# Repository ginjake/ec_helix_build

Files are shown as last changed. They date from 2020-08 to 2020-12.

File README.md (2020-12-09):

## LICENSE
creative commons non commercial

商用利用したい場合は twitter @sirojake にご相談ください  
please contact me for commercial use.
## developer 
ginjake

## 静電容量Helixとは？
Helix Keyboardの基板を差し替え、静電容量スイッチに対応させる為の基板です   
Varmiloスイッチ用とラバードーム用の2種類があり、別々の基板になっています。

## 外部の使用ライブラリ
### シンボルライブラリー
phi-kbd-library-master https://github.com/zk-phi/phi-kbd-library  
kbd https://github.com/foostan/kbd  

### フットプリントライブラリー
kbd https://github.com/foostan/kbd  
phi-kbd-library-master https://github.com/zk-phi/phi-kbd-library  
rd https://github.com/KiCad/kicad-footprints/tree/master/Resistor_SMD.pretty  
cs　https://github.com/KiCad/kicad-footprints/tree/master/Capacitor_SMD.pretty  

# 組み立て方 
本家Helixとの共通部分については省略しています。  
Varmilo版とラバードームで共通箇所が多いため、まとめて記載しています。

こちらのビルドログも参考になるので、目を通しておくと良いかもしれません  
https://orumin.blogspot.com/2020/10/helix-ec-helix-niz-ver.html

## 注意
本キットは組み立て難易度が高く、使うパーツも特殊です。  
自作キーボード初心者の方にはおすすめしません。  
通常のメカニカルスイッチでは動作せず、特殊なスイッチが必要になります。

# Varmiloスイッチについて
Varmilo社が出しているスイッチで、静電容量メカニカルとも呼ばれています。  
単体では販売されていないので、既製品を分解して入手する必要があります。  
ふもっふのお店のカスタムキーボードサービスで
デイジー軸 桜軸 ローズ軸などを選択して発注するのが一番手軽です。
https://jp.varmilo.com/keyboardproscenium/

# ラバードームスイッチについて
HHKBやREAL FORCE、NiZで採用されている方式です。  
トップハウジング、ステム、ラバードーム、コニックリングで構成されており、  
NiZキーボードを購入して分解することで全て手に入れることが出来ます。

## 部品

下記は両手分を作るのに必要なパーツ数です  

### 本家 Varmilo ラバードーム共通部品
| 名前 | 数 | 備考 |
| ---- | ---- | --- |
| Pro Micro | 2個 | |
| TRRSジャック | 2個 | |
| タクトスイッチ | 2個 | |
| スプリングピンヘッダ 12P | 4個 | コンスルーとも呼ばれています |
| プレート | 2セット| 遊舎工房の切り出しサービスがおすすめです|
| OLED保護プレート | 2枚 | |
| ゴム足 | 12個 |  |
| キーキャップ | 64個 | CherryMX軸 |
| 3.5mmオーディオケーブル | 左右合わせて1本 | 左右のキーボード接続用 |
| micro USBケーブル | 左右あわせて1本 | 
| OLEDモジュール | 2個 | OLED用（オプション） |
| ピンソケット 4P | 2個 | OLED用（オプション） |
| ピンヘッダ 4P | 2個 | OLED用（オプション） |
| M2スペーサー 8mm | 4個 | (OLED用)|
| sk6812mini| varmilo版 64個,ラバードーム版 54個  | LEDを付ける場合のみ|

### ラバードーム版追加部品
| 名前 | 数 | 備考 |
| ---- | ---- | --- |
| M5スペーサー | 8個 | |
| M2用ワッシャ | 8個(適宜) | |
| M2スペーサー 7mm| 8個 | |
| M2ネジ 4mm| 16個 | (低頭のほうが望ましい)|
| M2ネジ 6mm| 8個 | (低頭のほうが望ましい)|

### 本家と異なる部品
| 名前 | 数 | 備考 | 入手先 |
| ---- | ---- | --- | ---- |
| PCB | 2枚 | | |
| 静電容量キースイッチ | 64個 | 詳しくは後述します | |
| スイッチソケット | 64個 | varmilo版のみ https://yushakobo.jp/shop/a01ps/ | |
| 1608(0603)チップ抵抗 100K | 14 | | https://www.sengoku.co.jp/mod/sgk_cart/detail.php?code=EEHD-57HD |
| 1608(0603)チップ抵抗 10K | 4 | | https://www.sengoku.co.jp/mod/sgk_cart/detail.php?code=EEHD-57GX |
| 1608(0603)チップ抵抗 1KΩ | 4| | https://www.sengoku.co.jp/mod/sgk_cart/detail.php?code=EEHD-57GK |
| 1608(0603)チップ抵抗 200Ω | 12 | | https://www.sengoku.co.jp/mod/sgk_cart/detail.php?code=EEHD-57FZ |
| 1608(0603)チップ抵抗 51KΩ | 2 | | https://www.sengoku.co.jp/mod/sgk_cart/detail.php?code=EEHD-57H7 |
| 1608チップ積層セラミックコンデンサー 50Vdc 220pF | 2 | GRM1882C1H221JA01D*A (10個入り)| https://www.marutsu.co.jp/GoodsDetail.jsp?salesGoodsCode=19297&shopNo=3 |
|チップトランジスタ　2SC2712-GR 50V150m | 2 | | http://akizukidenshi.com/catalog/g/gI-00761/ |
| 74HC4051DB IC MUX/DEMUX 8X1 16SSOP | 2 | | https://www.marutsu.co.jp/pc/i/24340308/ |
| 2回路入オペアンプAD8616ARM | 2 | | http://akizukidenshi.com/catalog/g/gI-04570/ |
| ジャンパ用の銅線 | 少し | | |

### Varmilo版用キースイッチ
対応スイッチはVarmiloのECスイッチのみです。  
V1でもV2でも動作します。  

### Niz版用キースイッチ
メカニカルスイッチと異なり、複数のパーツが組み合わさって機能します。

| 名前  | 主な入手先 |
| ----  | ---- |
| 軸＆ハウジング  | https://www.nizkeyboard.com/collections/ornaments/products/2019-new-niz-ec-switch |
| ラバードーム  |  https://www.keyclack.com/products/bke-topre-dome-replacements?_pos=2&_sid=6025d869e&_ss=r もしくはREAL FORCEやNiz、HHKBから解体 |
| コニックリング | REAL FORCEやNiz、HHKB等から解体、もしくは https://btoshop.jp/2020/09/25/adelcps/ |

### ビットトレード版のスイッチについて
コニックリングとラバードームのみ対応しています。  
外形がcherryMXの企画と比べて若干大きいため、プレートが割れるなどの可能性があります。  
(アクリルカットサービスのモノは入りましたが、初期版のモノでは割れてしまいました。)  
ワッシャーが入らない等の問題もあるのでハウジングは使わず、コニックリングの回収に留めておくのが無難かもしれません。 
スペーサーやネジ、プレートを調整すれば使えるとは思います。  

## 追加で必要な工具
| 名前 | 数 | 備考 | 入手先 |
| ---- | ---- | --- | ---- |
| 絶縁テープ | 1つ | | |
| フラックス | 1つ | | |
| 拡大用ルーペ | 1つ | | |
| 懐中電灯 | 1つ | | |

## 組み立て方
右手用と左手用で若干異なります。  
写真は基本的にVarmilo版ですが、ラバードーム版でもほぼ同じです。    
ラバードーム版とVarmilo版はスイッチ部分のフットプリントが異なるだけです。   

__一度全ての工程を読み、理解してから作業を進めることをお勧めします。__

OLED,TRRSジャック等のHelixの共通部分については省略します。  
LEDについてはbacklightのみの対応です。  
(Varmilo版とラバードーム版で数が異なります)

## 絶縁テープとジャンパ(左手側のみ)
将来的にProMicroが刺さるところに絶縁テープを貼ります  


絶縁テープの上から、写真のようにジャンパしていきます。
この作業は左手側のみで、右手は不要です。   


ジャンパが完了したら、その上からさらに絶縁テープを貼った方が安心です。

また、絶縁テープを貼らず、ProMicro側を表裏逆転させる方法もありますが  
OLED用のスペーサーの高さが変わってしまうのであまりおすすめしません。

## その他のパーツを実装する
基板に書いてある通りにパーツを実装します。
IMAG7291

74HC4051DB　と オペアンプAD8616ARMの向きには注意してください。  
チップ側の黒い丸上の凹みと、基板上のコの時のシルクが合わさるように置くのが正解です。  
隣のピンとショートしていないか、懐中電灯で照らしながらルーペで確認しておくのがおすすめです。


## リセットスイッチ
本家と同じです。

## スイッチソケットをつける(Varmilo版)
Varmilo版の場合、全てのキーにスイッチソケットをつけていきます。


## OLEDをつける(オプション)
本家と同じです

## TRRSジャックをつける
両手分つくる場合は必要になります。  
本家と同じです

## ProMicro
本家と同じです。

## ProMicroにqmkを焼く
下記のファームウェアを焼く必要があります。  
現在はNiz版とVarmilo版は同じファームになっています。   
https://github.com/ginjake/qmk_firmware/tree/ec_helix_niz   
``make ec_helix:test:avrdude`` もしくは 
``make ec_helix:ginjake:avrdude`` 

## トッププレート Varmilo版
トッププレートとスペーサーをネジ(短い方)で固定したら、向きに注意してスイッチを埋めていきます。

## トッププレート ラバードーム版
トッププレートにワッシャとスペーサーをネジ(短い方)で固定してから、スイッチをアクリルに差込みます。  
ワッシャはスペーサー1つに対して1枚が基本ですが、ネジやスペーサーの長さ、アクリルの太さによって変化します。
このあたりは適宜調整してください。
ネジ→トッププレート→ワッシャ→スペーサー　のような順番になるように固定しましょう。  
中に軸を入れてラバードームでフタをします。  
スペーサーとラバードームが干渉しないよう、ハサミで切りましょう  
ラバードームの凹みの中にコニックリングを入れます。  


このとき、コニックリングが重ね合っていないか気を付けましょう。  
複数個が重なっていても意外と気付かず、誤作動の原因になります。  

## ボトムプレート(ラバードーム版)
基板とボトムプレートの間にM5スペーサーが入るようにネジ止め(長い方)しましょう。  
Varmilo版は普通にネジで止めてしまって大丈夫です。


## 完成


## qmkコンパイル時の諸注意
・OLEDをつけない場合は `rule.mk` の `OLED_DRIVER_ENABLE` を `no` にしてください。 
無駄な負荷がかかり、取りこぼしが発生する可能性が高くなります。   
・Varmilo版とラバードーム版でledの数が異なります。 `config.h` の `RGBLED_NUM` の数を適宜変更してください

・ステンレスプレートを使う場合は　`config.h` の `#define STAINLESS_PLATE` のコメントアウトを外してください。ステンレスプレートは実験的な対応の為、動作保証対象外となります。

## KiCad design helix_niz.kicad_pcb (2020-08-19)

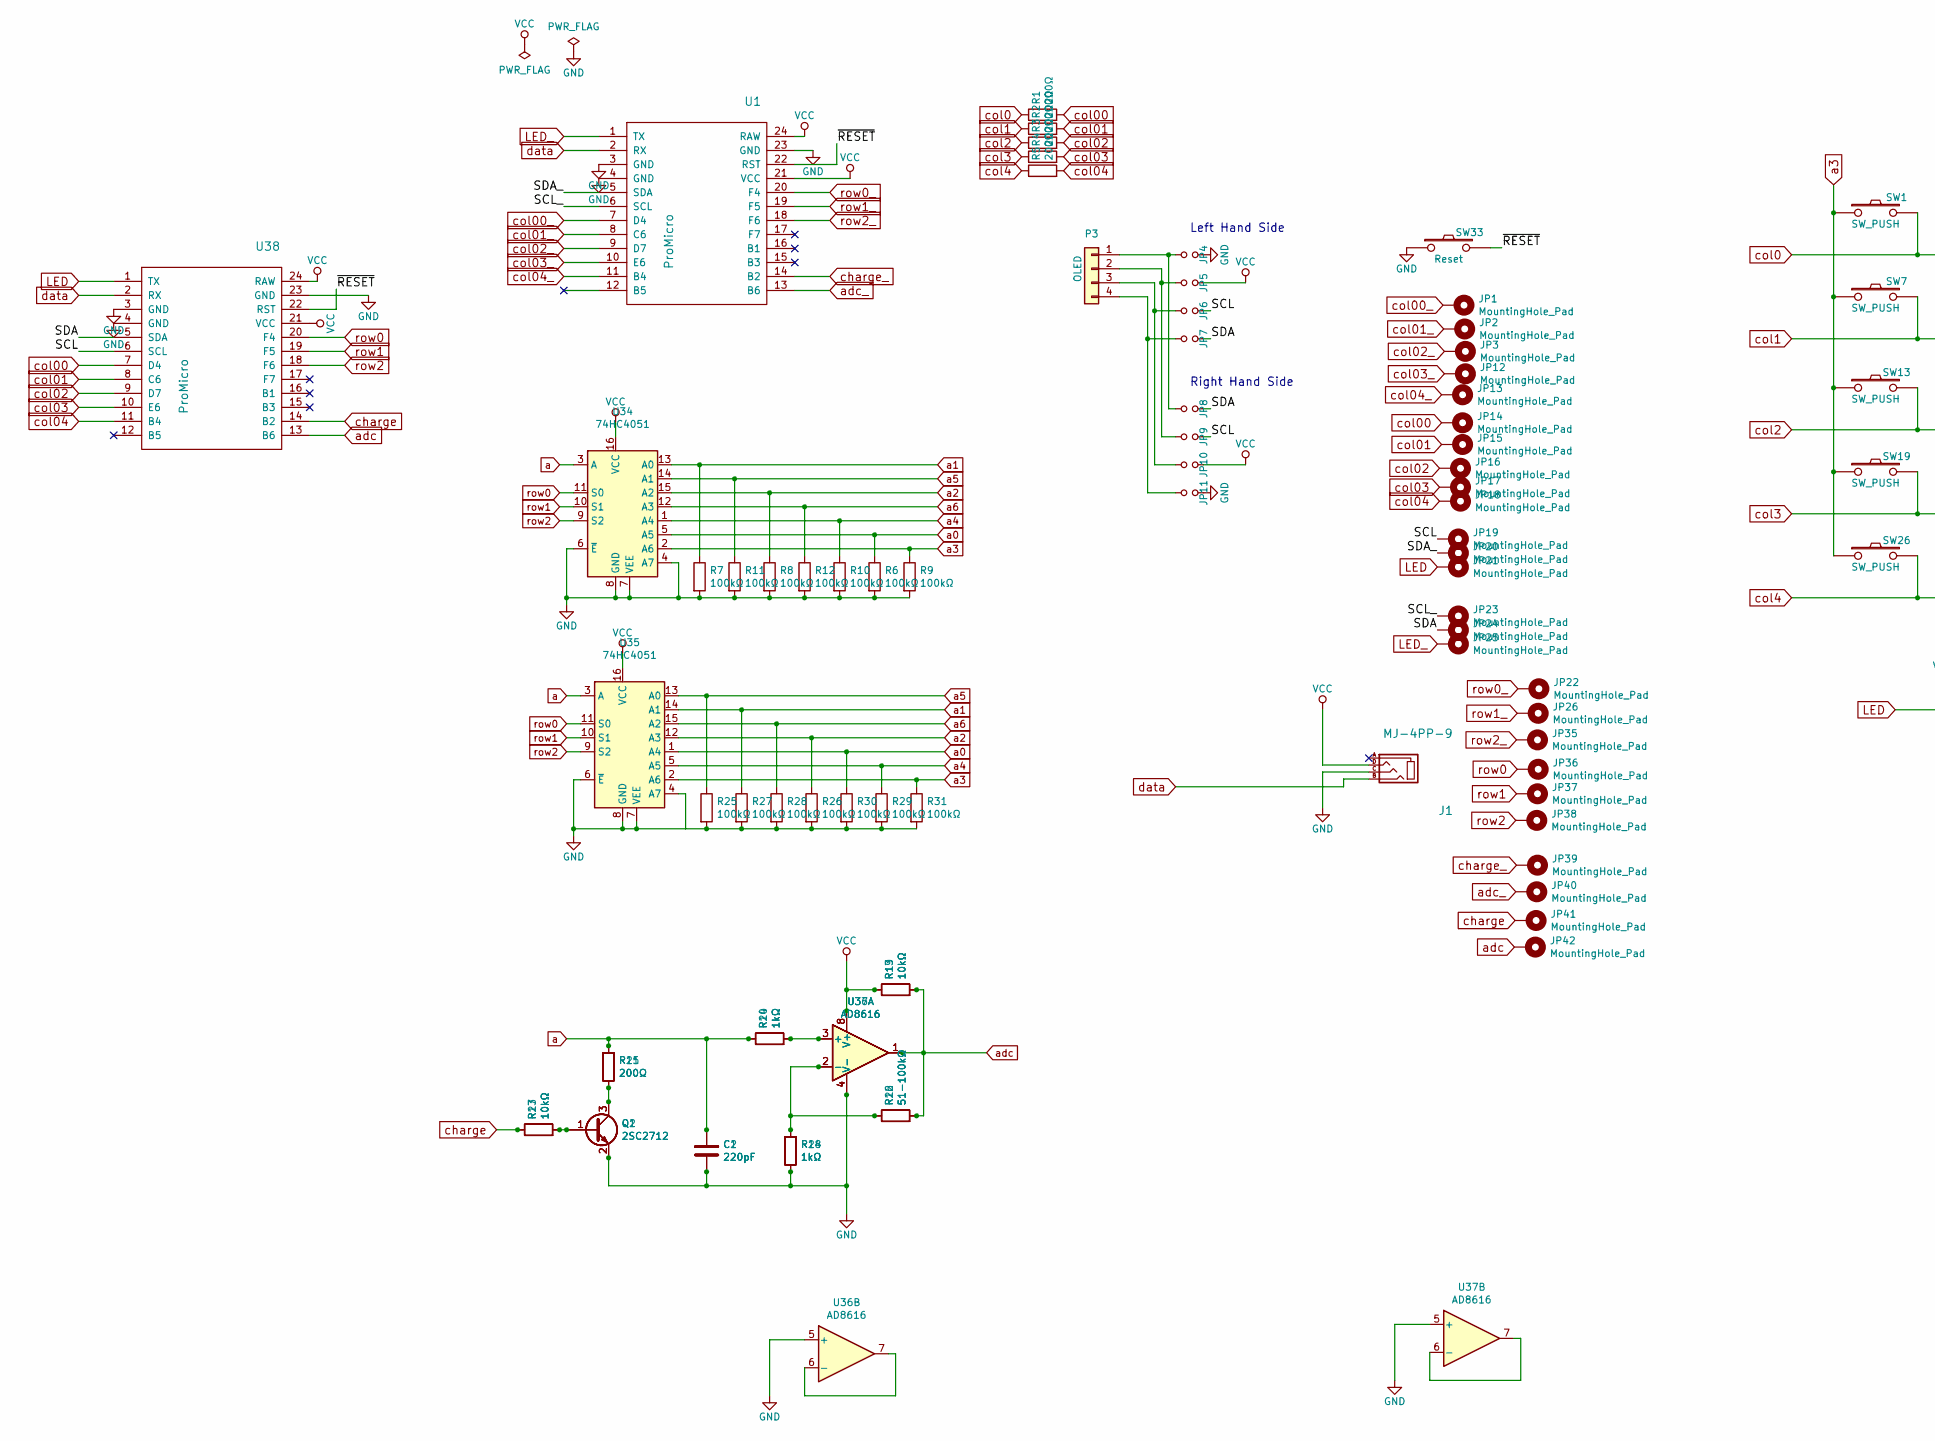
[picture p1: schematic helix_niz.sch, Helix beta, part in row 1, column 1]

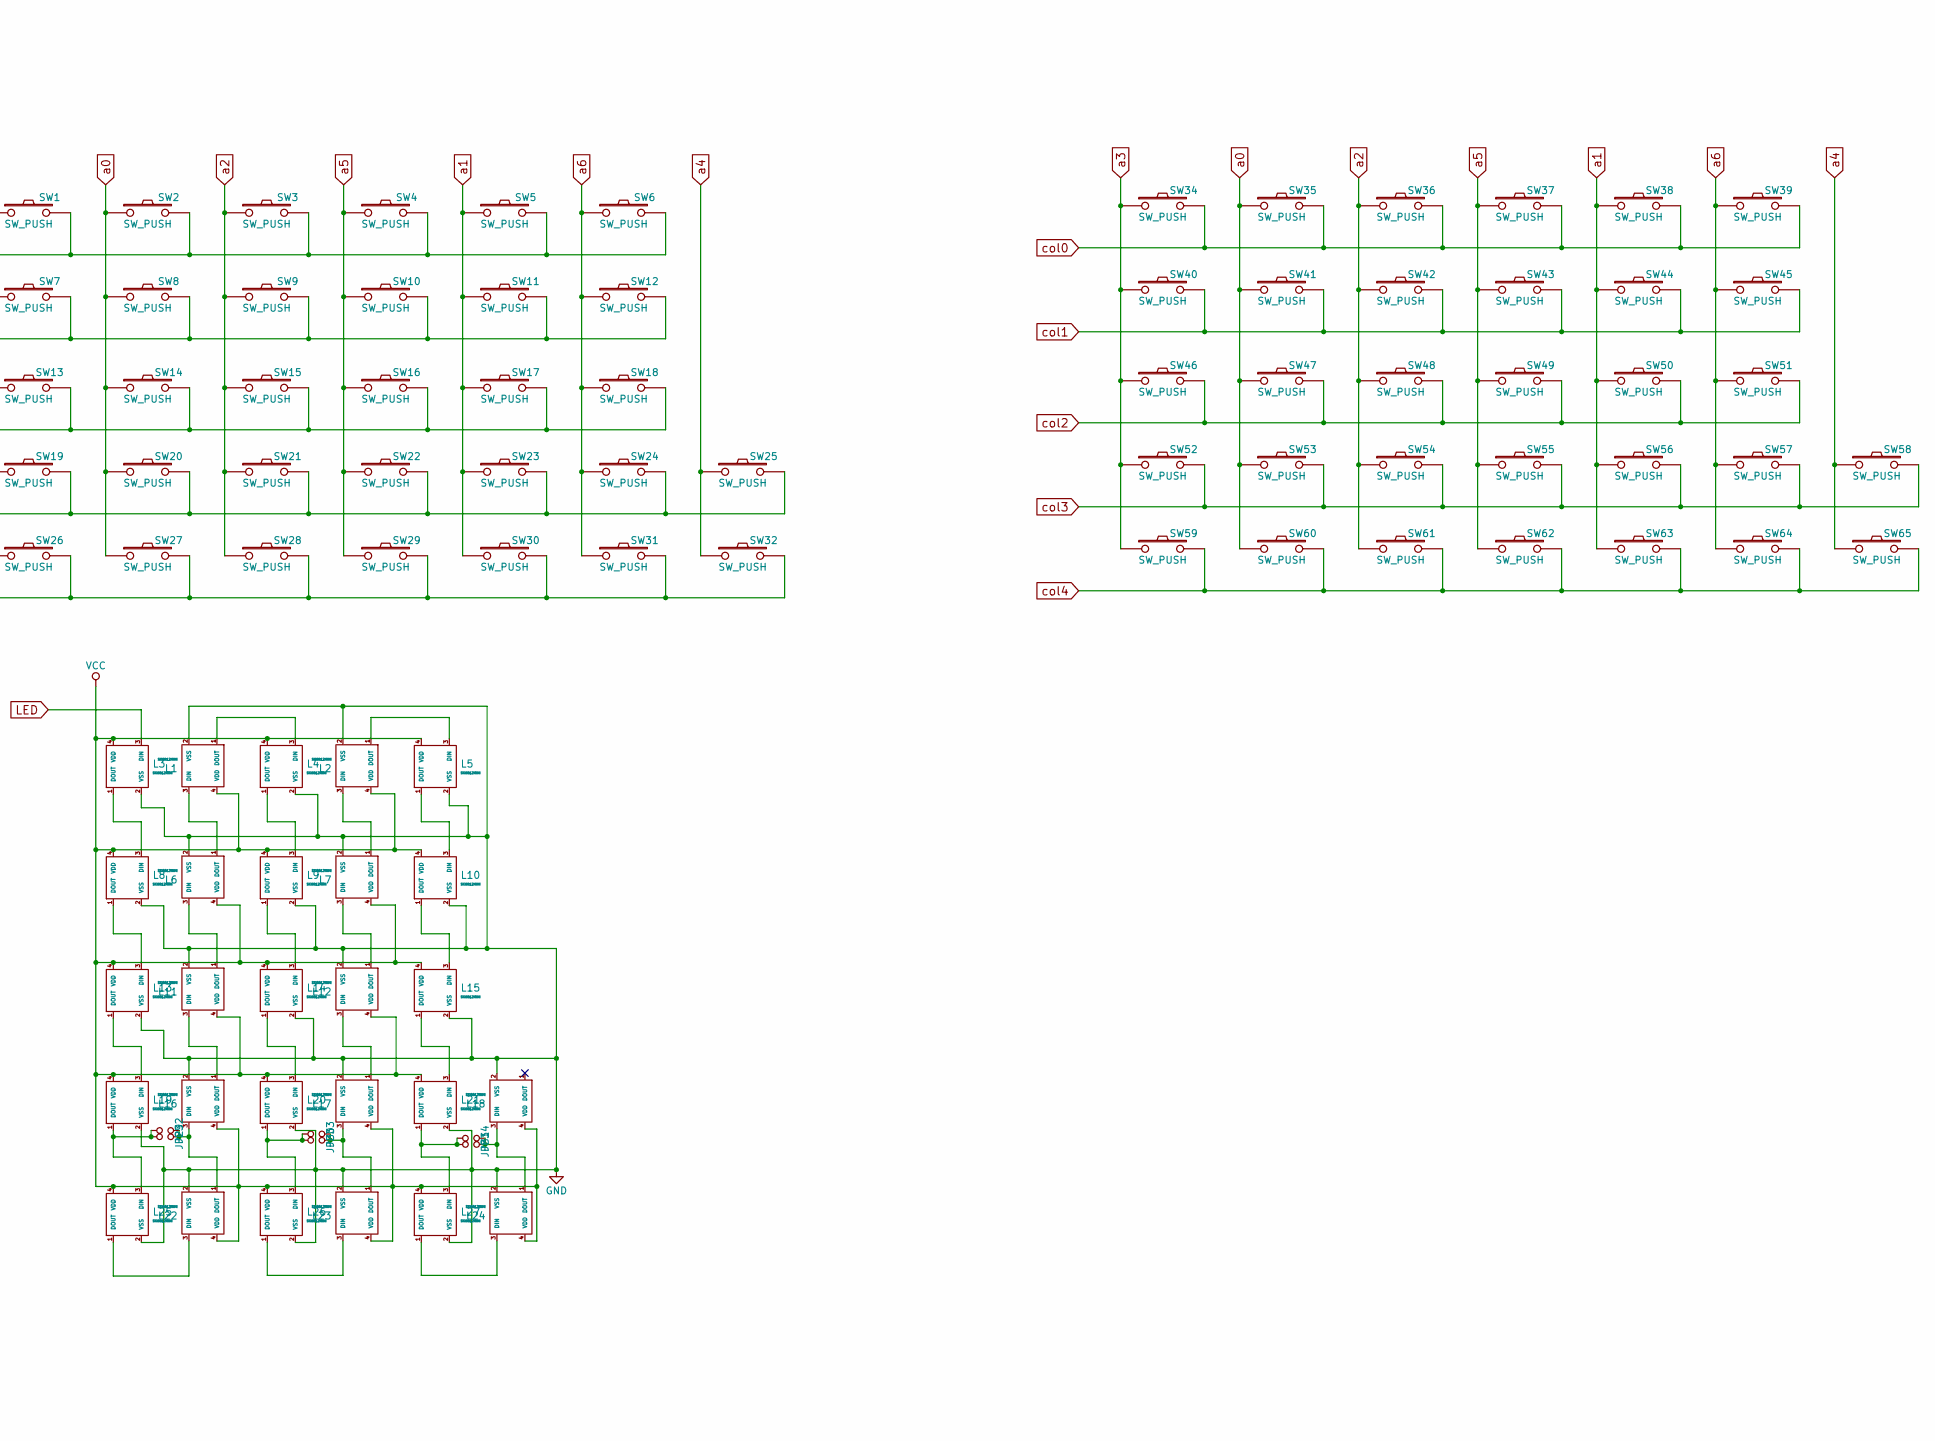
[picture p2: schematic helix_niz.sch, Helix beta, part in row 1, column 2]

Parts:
C1, C2: 220pF; C_0603_1608Metric
J1: MJ-4PP-9
JP1, JP2, JP3, JP12, JP13, JP14, JP15, JP16, JP17, JP18, JP19, JP20, JP21, JP22, JP23, JP24, JP25, JP26, JP35, JP36, JP37, JP38, JP39, JP40, JP41, JP42: MountingHole_Pad; THSmallest
JP4, JP11, JP29, JP30, JP31, JP32, JP33, JP34: GND; Jumper
JP5, JP10: VCC; Jumper
JP6, JP9: SCL; Jumper
JP7, JP8: SDA; Jumper
L1, L2, L3, L4, L5, L6, L7, L8, L9, L10, L11, L12, L13, L14, L15, L16, L17, L18, L19, L20, L21, L22, L23, L24, L25, L26, L27: SK6812MINI; SK6812MINI_rev
P3: OLED
Q1, Q2: 2SC2712
R1, R2, R3, R4, R5, R15, R21: 200Ω; R_0603_1608Metric
R6, R7, R8, R9, R10, R11, R12, R25, R26, R27, R28, R29, R30, R31: 100kΩ; R_0603_1608Metric
R13, R17, R19, R23: 10kΩ; R_0603_1608Metric
R14, R18, R20, R24: 1kΩ; R_0603_1608Metric
R16, R22: 51-100kΩ; R_0603_1608Metric
SW1, SW2, SW3, SW4, SW5, SW6, SW7, SW8, SW9, SW10, SW11, SW12, SW13, SW14, SW15, SW16, SW17, SW18, SW19, SW20, SW21, SW22, SW23, SW24, SW25, SW26, SW27, SW28, SW29, SW30, SW31, SW32, SW34, SW35, SW36, SW37, SW38, SW39, SW40, SW41, SW42, SW43, SW44, SW45, SW46, SW47, SW48, SW49, SW50, SW51, SW52, SW53, SW54, SW55, SW56, SW57, SW58, SW59, SW60, SW61, SW62, SW63, SW64, SW65: SW_PUSH; niz
SW33: Reset; ResetSW
U1, U38: ProMicro; ProMicro_v3.5
U34, U35: 74HC4051; SSOP16
U36, U37: AD8616

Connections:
/SCL: JP6.2, JP9.2, JP19.1, U38.6 (SCL)
/SCL_: JP23.1, U1.6 (SCL)
/SDA: JP7.2, JP8.2, JP24.1, U38.5 (SDA)
/SDA_: JP20.1, U1.5 (SDA)
/~RESET: SW33.2, U1.22 (RST), U38.22 (RST)
GND: C1.2, C2.2, J1.C, JP4.2, JP11.2, L1.2 (VSS), L2.2 (VSS), L3.2 (VSS), L4.2 (VSS), L5.2 (VSS), L6.2 (VSS), L7.2 (VSS), L8.2 (VSS), L9.2 (VSS), L10.2 (VSS), L11.2 (VSS), L12.2 (VSS), L13.2 (VSS), L14.2 (VSS), L15.2 (VSS), L16.2 (VSS), L17.2 (VSS), L18.2 (VSS), L19.2 (VSS), L20.2 (VSS), L21.2 (VSS), L22.2 (VSS), L23.2 (VSS), L24.2 (VSS), L25.2 (VSS), L26.2 (VSS), L27.2 (VSS), Q1.2 (E), Q2.2 (E), R6.2, R7.2, R8.2, R9.2, R10.2, R11.2, R12.2, R18.2, R24.2, R25.2, R26.2, R27.2, R28.2, R29.2, R30.2, R31.2, SW33.1, U1.3 (GND), U1.4 (GND), U1.23 (GND), U34.4 (A7), U34.6 (~E), U34.7 (VEE), U34.8 (GND), U35.4 (A7), U35.6 (~E), U35.7 (VEE), U35.8 (GND), U36.4 (V-), U36.5 (+), U37.4 (V-), U37.5 (+), U38.3 (GND), U38.4 (GND), U38.23 (GND)
LED: JP21.1, L3.3 (DIN), U38.1 (TX)
LED_: JP25.1, U1.1 (TX)
unnamed: JP4.1, JP8.1, P3.1
unnamed: JP5.1, JP9.1, P3.2
unnamed: JP6.1, JP10.1, P3.3
unnamed: JP7.1, JP11.1, P3.4
unnamed: JP29.1, JP32.1, L19.1 (DOUT), L25.3 (DIN)
unnamed: JP29.2, JP32.2, L16.3 (DIN), L22.1 (DOUT)
unnamed: JP30.1, JP33.1, L20.1 (DOUT), L26.3 (DIN)
unnamed: JP30.2, JP33.2, L17.3 (DIN), L23.1 (DOUT)
unnamed: JP31.1, JP34.1, L21.1 (DOUT), L27.3 (DIN)
unnamed: JP31.2, JP34.2, L18.3 (DIN), L24.1 (DOUT)
unnamed: L1.1 (DOUT), L4.3 (DIN)
unnamed: L1.3 (DIN), L6.1 (DOUT)
unnamed: L2.1 (DOUT), L5.3 (DIN)
unnamed: L2.3 (DIN), L7.1 (DOUT)
unnamed: L3.1 (DOUT), L8.3 (DIN)
unnamed: L4.1 (DOUT), L9.3 (DIN)
unnamed: L10.1 (DOUT), L15.3 (DIN)
unnamed: L5.1 (DOUT), L10.3 (DIN)
unnamed: L6.3 (DIN), L11.1 (DOUT)
unnamed: L11.3 (DIN), L16.1 (DOUT)
unnamed: L7.3 (DIN), L12.1 (DOUT)
unnamed: L12.3 (DIN), L17.1 (DOUT)
unnamed: L13.1 (DOUT), L19.3 (DIN)
unnamed: L8.1 (DOUT), L13.3 (DIN)
unnamed: L14.1 (DOUT), L20.3 (DIN)
unnamed: L9.1 (DOUT), L14.3 (DIN)
unnamed: L15.1 (DOUT), L21.3 (DIN)
unnamed: L22.3 (DIN), L25.1 (DOUT)
unnamed: L23.3 (DIN), L26.1 (DOUT)
unnamed: L24.3 (DIN), L27.1 (DOUT)
unnamed: Q1.1 (B), Q2.1 (B), R17.2, R23.2
unnamed: Q1.3 (C), Q2.3 (C), R15.2, R21.2
unnamed: R14.2, R20.2, U36.3 (+), U37.3 (+)
unnamed: R16.1, R18.1, R22.1, R24.1, U36.2 (-), U37.2 (-)
unnamed: U36.6 (-), U36.7
unnamed: U37.6 (-), U37.7
VCC: J1.D, JP5.2, JP10.2, L1.4 (VDD), L2.4 (VDD), L3.4 (VDD), L4.4 (VDD), L5.4 (VDD), L6.4 (VDD), L7.4 (VDD), L8.4 (VDD), L9.4 (VDD), L10.4 (VDD), L11.4 (VDD), L12.4 (VDD), L13.4 (VDD), L14.4 (VDD), L15.4 (VDD), L16.4 (VDD), L17.4 (VDD), L18.4 (VDD), L19.4 (VDD), L20.4 (VDD), L21.4 (VDD), L22.4 (VDD), L23.4 (VDD), L24.4 (VDD), L25.4 (VDD), L26.4 (VDD), L27.4 (VDD), R13.1, R19.1, U1.21 (VCC), U1.24 (RAW), U34.16 (VCC), U35.16 (VCC), U36.8 (V+), U37.8 (V+), U38.21 (VCC), U38.24 (RAW)
a: C1.1, C2.1, R14.1, R15.1, R20.1, R21.1, U34.3 (A), U35.3 (A)
a0: R6.1, R30.1, SW2.1, SW8.1, SW14.1, SW20.1, SW27.1, SW35.1, SW41.1, SW47.1, SW53.1, SW60.1, U34.5 (A5), U35.1 (A4)
a1: R7.1, R27.1, SW5.1, SW11.1, SW17.1, SW23.1, SW30.1, SW38.1, SW44.1, SW50.1, SW56.1, SW63.1, U34.13 (A0), U35.14 (A1)
a2: R8.1, R26.1, SW3.1, SW9.1, SW15.1, SW21.1, SW28.1, SW36.1, SW42.1, SW48.1, SW54.1, SW61.1, U34.15 (A2), U35.12 (A3)
a3: R9.1, R31.1, SW1.1, SW7.1, SW13.1, SW19.1, SW26.1, SW34.1, SW40.1, SW46.1, SW52.1, SW59.1, U34.2 (A6), U35.2 (A6)
a4: R10.1, R29.1, SW25.1, SW32.1, SW58.1, SW65.1, U34.1 (A4), U35.5 (A5)
a5: R11.1, R25.1, SW4.1, SW10.1, SW16.1, SW22.1, SW29.1, SW37.1, SW43.1, SW49.1, SW55.1, SW62.1, U34.14 (A1), U35.13 (A0)
a6: R12.1, R28.1, SW6.1, SW12.1, SW18.1, SW24.1, SW31.1, SW39.1, SW45.1, SW51.1, SW57.1, SW64.1, U34.12 (A3), U35.15 (A2)
adc: JP42.1, R13.2, R16.2, R19.2, R22.2, U36.1, U37.1, U38.13 (B6)
adc_: JP40.1, U1.13 (B6)
charge: JP41.1, R17.1, R23.1, U38.14 (B2)
charge_: JP39.1, U1.14 (B2)
col0: R1.1, SW1.2, SW2.2, SW3.2, SW4.2, SW5.2, SW6.2, SW34.2, SW35.2, SW36.2, SW37.2, SW38.2, SW39.2; also elsewhere on the board
col00: JP14.1, R1.2, U38.7 (D4); also elsewhere on the board
col00_: JP1.1, U1.7 (D4)
col1: R2.1, SW7.2, SW8.2, SW9.2, SW10.2, SW11.2, SW12.2, SW40.2, SW41.2, SW42.2, SW43.2, SW44.2, SW45.2; also elsewhere on the board
col01: JP15.1, R2.2, U38.8 (C6); also elsewhere on the board
col01_: JP2.1, U1.8 (C6)
col2: R3.1, SW13.2, SW14.2, SW15.2, SW16.2, SW17.2, SW18.2, SW46.2, SW47.2, SW48.2, SW49.2, SW50.2, SW51.2; also elsewhere on the board
col02: JP16.1, R3.2, U38.9 (D7); also elsewhere on the board
col02_: JP3.1, U1.9 (D7)
col3: R4.1, SW19.2, SW20.2, SW21.2, SW22.2, SW23.2, SW24.2, SW25.2, SW52.2, SW53.2, SW54.2, SW55.2, SW56.2, SW57.2, SW58.2; also elsewhere on the board
col03: JP17.1, R4.2, U38.10 (E6); also elsewhere on the board
col03_: JP12.1, U1.10 (E6)
col4: R5.1, SW26.2, SW27.2, SW28.2, SW29.2, SW30.2, SW31.2, SW32.2, SW59.2, SW60.2, SW61.2, SW62.2, SW63.2, SW64.2, SW65.2; also elsewhere on the board
col04: JP18.1, R5.2, U38.11 (B4); also elsewhere on the board
col04_: JP13.1, U1.11 (B4)
data: J1.B, U1.2 (RX), U38.2 (RX)
row0: JP36.1, U34.11 (S0), U35.11 (S0), U38.20 (F4)
row0_: JP22.1, U1.20 (F4)
row1: JP37.1, U34.10 (S1), U35.10 (S1), U38.19 (F5)
row1_: JP26.1, U1.19 (F5)
row2: JP38.1, U34.9 (S2), U35.9 (S2), U38.18 (F6)
row2_: JP35.1, U1.18 (F6)

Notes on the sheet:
Left Hand Side
Right Hand Side

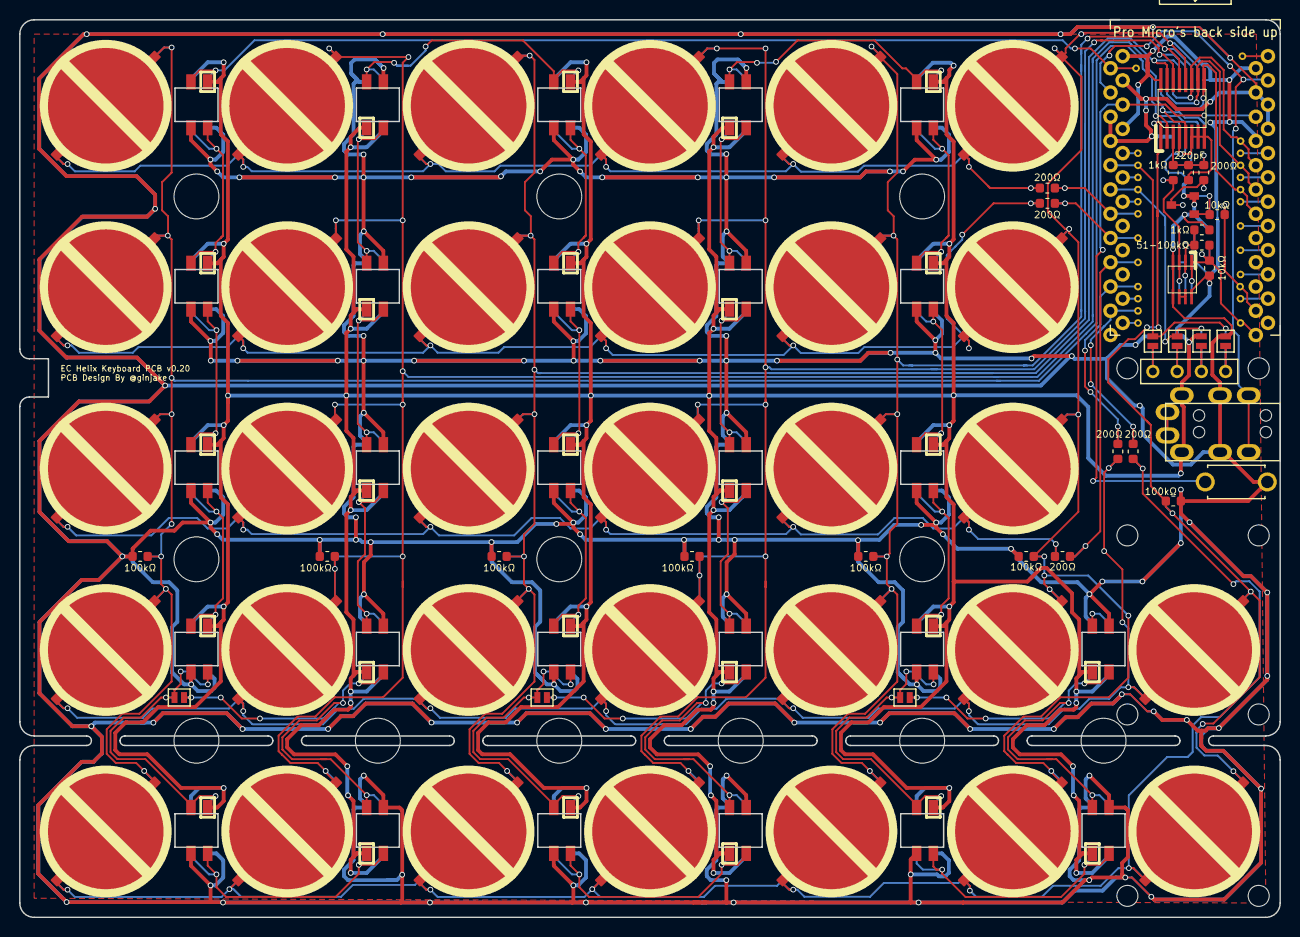
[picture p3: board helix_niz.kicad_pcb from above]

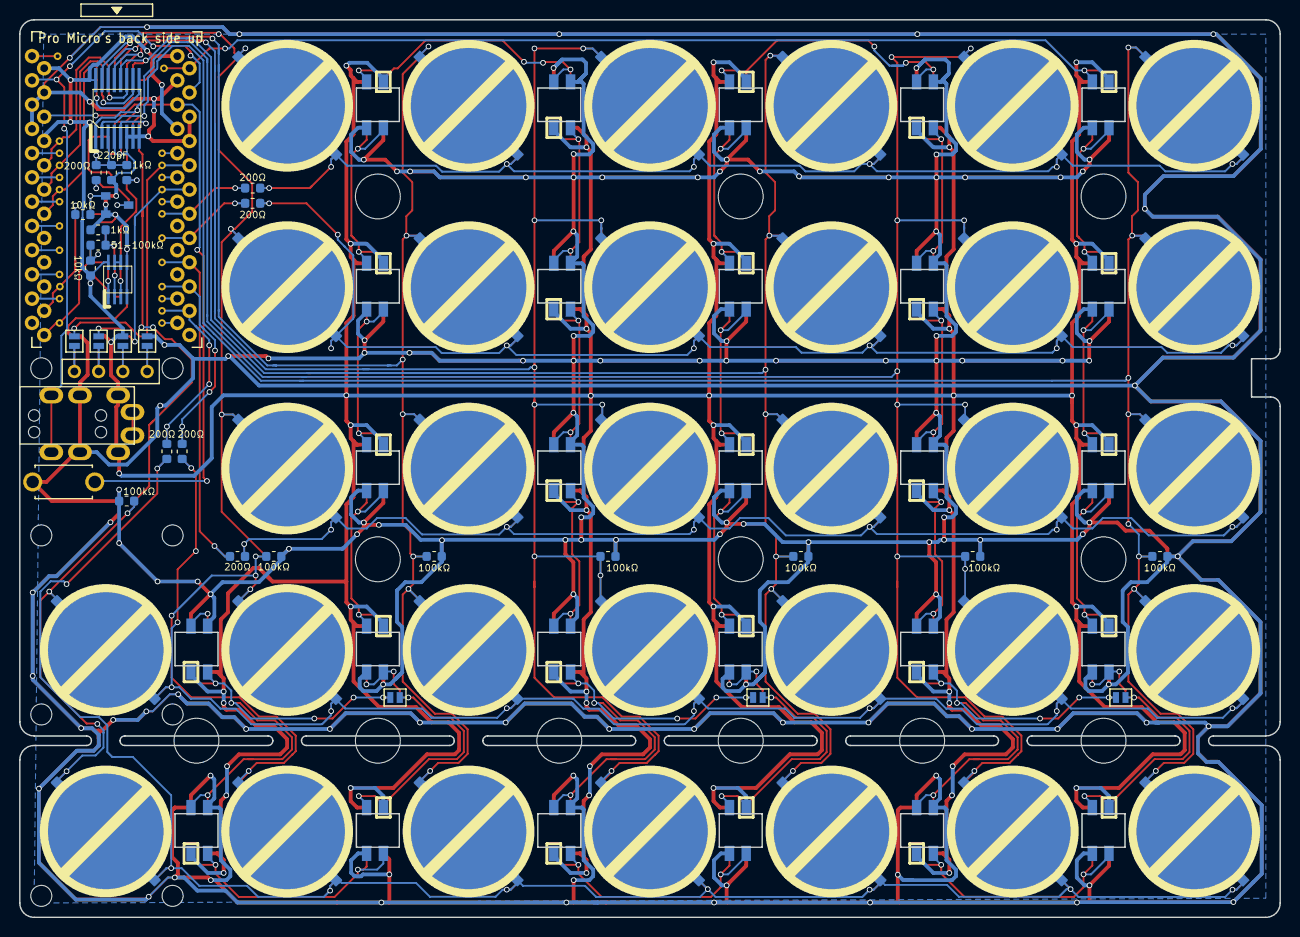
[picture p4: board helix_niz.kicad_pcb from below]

Board: 2 copper layers, 132.0 x 94.0 mm, 200 parts (62 on the bottom side), 79 nets.

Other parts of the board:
HOLE_3M, HOLE_3M#2, HOLE_3M#3, HOLE_3M#4, HOLE_3M#5, HOLE_3M#6, HOLE_3M#7, HOLE_3M#8, HOLE_3M#9, HOLE_3M#10, HOLE_3M#11, HOLE_3M#12: VAL**; HOLE_M2_TH
HOLE_M2, HOLE_M2#2, HOLE_M2#3, HOLE_M2#4, HOLE_M2#5, HOLE_M2#6, HOLE_M2#7, HOLE_M2#8: VAL**; HOLE_M2
R32, R33, R34, R35, R36: 200Ω; R_0603_1608Metric

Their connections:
col0: R32.1; also elsewhere on the board
col00: R32.2; also elsewhere on the board
col1: R33.1; also elsewhere on the board
col01: R33.2; also elsewhere on the board
col2: R34.1; also elsewhere on the board
col02: R34.2; also elsewhere on the board
col3: R35.1; also elsewhere on the board
col03: R35.2; also elsewhere on the board
col4: R36.1; also elsewhere on the board
col04: R36.2; also elsewhere on the board

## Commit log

2020-06-20 コミット
    [helix-2020-04-11-19-55-44.sch, helix.kicad_pcb, helix.sch]
2020-08-19 ノイズ対策＆nizとvarmiloを同じリポジトリにした
    [helix-2020-04-11-19-55-44.sch, helix.kicad_pcb, helix.sch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]
